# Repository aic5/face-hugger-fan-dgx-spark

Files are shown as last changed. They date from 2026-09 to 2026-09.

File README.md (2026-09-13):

# Face Hugger Fan for NVIDIA DGX Spark

An open hardware and software project for adding a temperature-controlled
140 mm fan to an NVIDIA DGX Spark. A Raspberry Pi Pico W drives a standard
12 V Noctua NF-A14 PWM fan, tracks CPU/GPU temperature in a local dashboard, and accepts temperature
telemetry from a small Linux service running on the DGX Spark. 

The RPi Pico W controls the fan automatically following a temperature curve set in the dashboard. It only comes on when it is needed and the fan is powered by a USB port in the DGX directly. No opening the DGX. No excessive noise. It comes on as needed. Set and forget. 

The name of this repo comes from the printed fan mount and arms, which wrap around the DGX
Spark a little like a face hugger. It makes the DGX Spark not as pretty, but also about 4-5C cooler.

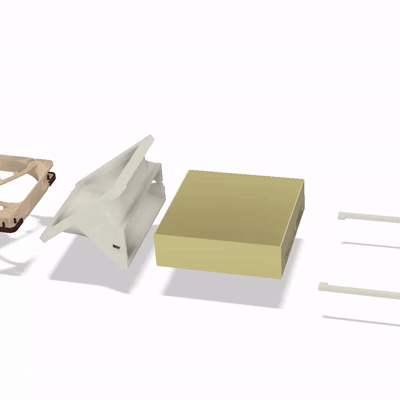
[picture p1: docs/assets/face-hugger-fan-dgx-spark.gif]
Animated exploded view of the Face Hugger Fan assembly


> [!CAUTION]
> This is an experimental, independently developed accessory. It is not endorsed
> by NVIDIA, Raspberry Pi, or Noctua, and it does not replace the DGX Spark's
> internal thermal management. Disconnect power before wiring. The fan motor is
> the only part of this design that receives 12 V. Use this at your own risk.

## Real build and printable parts

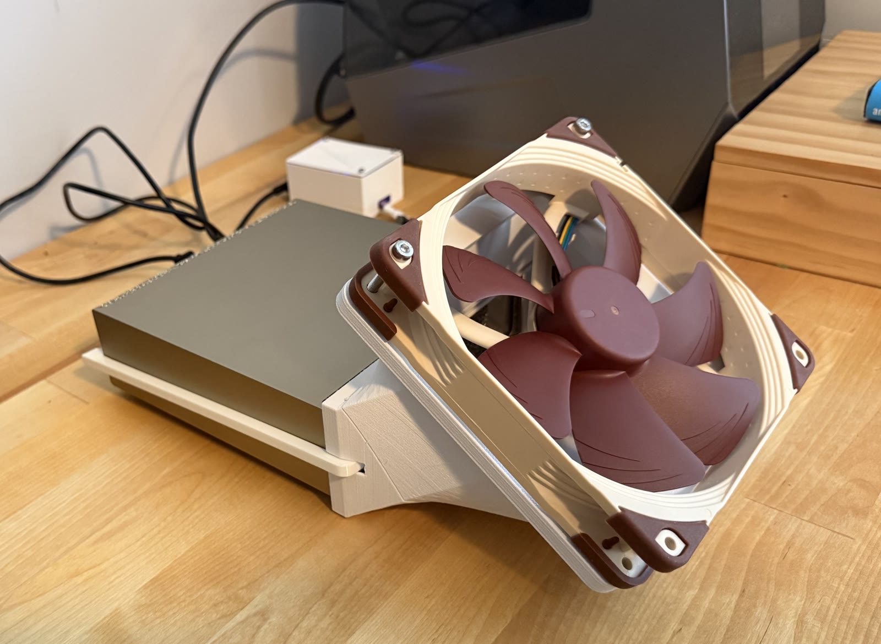
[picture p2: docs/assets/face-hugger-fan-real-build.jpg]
Assembled Face Hugger Fan mounted beside an NVIDIA DGX Spark


The photograph above shows the real assembled prototype. Both printable model
files are included in this repository:

- [Download the fan body / cover STL](hardware/stl/face-hugger-fan-dgx-spark-body.stl)
- [Download the two-arm set STL](hardware/stl/face-hugger-fan-dgx-spark-arms.stl)

See the [STL notes](hardware/stl/README.md) for dimensions, triangle counts,
checksums, scale guidance, and the current printing and assembly caveats.

## What is here

- Raspberry Pi Pico W CircuitPython firmware
- DGX Spark temperature collection and fan-control service
- Password-protected local web dashboard and temperature curve editor
- Illustrated wiring guide for the Pico W, boost converter, and 4-wire fan
- Bill of materials and fan specifications
- A quick-start installation guide
- Thermal comparison results with and without the external fan
- Printable body and mounting-arm STL files
- Desktop tests and continuous integration

## How it works

```mermaid
flowchart LR
    D[DGX Spark<br/>CPU and GPU sensors] -->|Wi-Fi telemetry<br/>and renewed commands| P[Raspberry Pi Pico W]
    U[5 V USB power] --> B[5 V to 12 V<br/>boost converter]
    U --> P
    B -->|12 V motor power| F[Noctua NF-A14 PWM]
    P -->|25 kHz PWM on GP15| F
    F -->|tach pulses on GP13| P
    P --> W[Local web dashboard]
```

The Pico starts at full fan speed and returns to full speed if commands expire.
The DGX service reads CPU/GPU temperatures, evaluates the configured stepped fan
curve, and renews the selected PWM command every five seconds by default.

## Dashboard

The Pico hosts a responsive local dashboard for live CPU/GPU temperature,
estimated fan speed, PWM output, fan-curve editing, and 24-hour history. The view
below uses synthetic readings from the repository's test fixture; it contains no
live credentials or private network information.

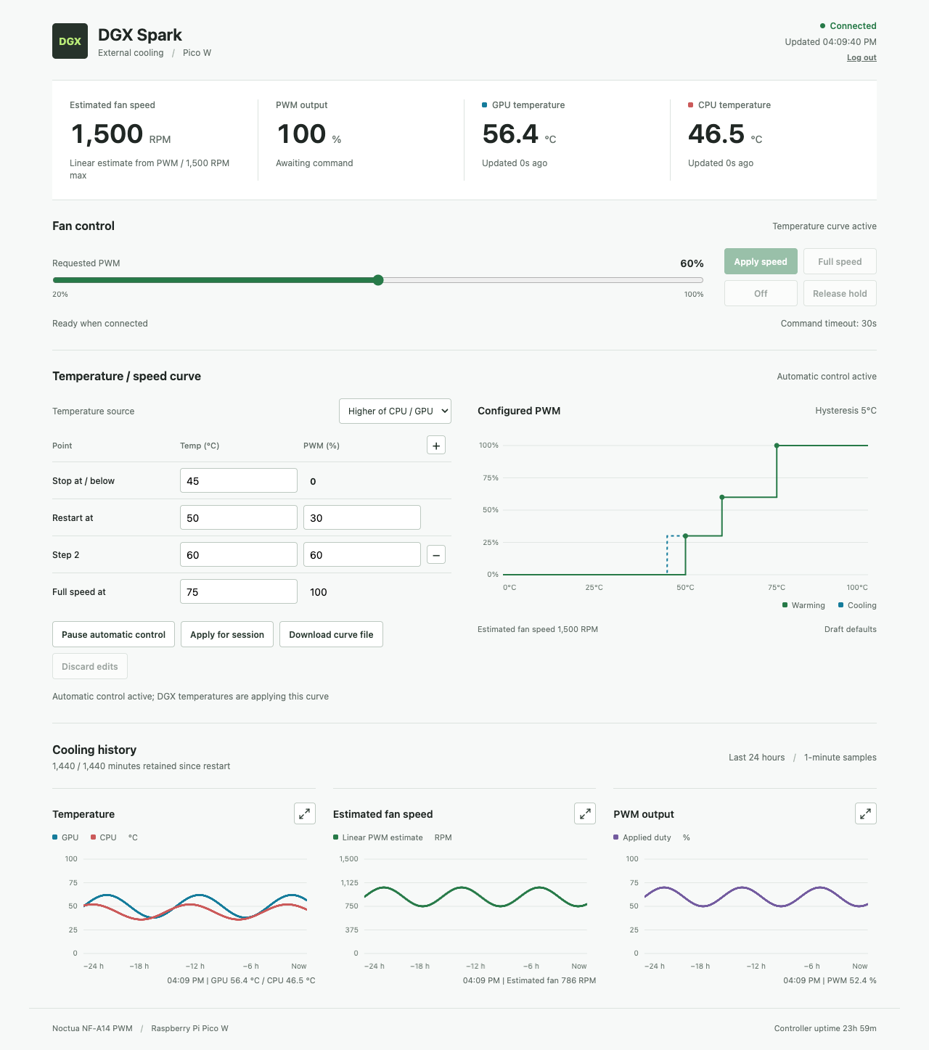
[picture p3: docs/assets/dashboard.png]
DGX Spark external fan controller dashboard


## Measured result

In the 13 September 2026 comparison, the external fan's clearest benefit was
lower peak temperature and less variation - not lower averages:

| Metric | GPU, no fan | GPU, with fan | Change | CPU, no fan | CPU, with fan | Change |
| --- | ---: | ---: | ---: | ---: | ---: | ---: |
| Maximum | 78.0 °C | 68.0 °C | **-10.0 °C** | 91.6 °C | 76.7 °C | **-14.9 °C** |
| Standard deviation | 11.2 °C | 7.3 °C | **-3.9 °C** | 14.8 °C | 9.3 °C | **-5.5 °C** |
| Average | 60.8 °C | 62.1 °C | +1.3 °C | 68.0 °C | 69.8 °C | +1.8 °C |

See [Thermal test results](docs/thermal-results.md) for all published statistics,
the original report, and the limitations of this comparison.

## Start here

### Parts links

The following Amazon links are affiliate links. I may receive a commission at
no additional cost to you if you make a purchase through them.

- [Noctua NF-A14 PWM computer fan](https://link.amazon/B0ex7c04A)
- [Raspberry Pi Pico W](https://amzn.to/4h3aFq5)
- [12 V DC boost converter](https://amzn.to/3UTugBN)

1. Read the [bill of materials](docs/bom.md) and obtain the parts.
2. Read the complete [illustrated wiring guide](docs/wiring.html) before connecting power.
3. Follow the [quick-start guide](docs/quick-start.md) to install the Pico firmware
   and the DGX service.
4. Review the [fan specifications](docs/fan-specifications.md) before substituting
   a different fan.
5. Read the [detailed software reference](docs/software-reference.md) for API,
   dashboard, fan-curve, failure-mode, and test documentation.

The printable body and two-arm set are available in [hardware/stl/](hardware/stl/).
STL files do not encode units, so read the model notes and verify dimensions in
your slicer before printing.

## Repository map

| Path | Contents |
| --- | --- |
| `code.py`, `fan_*.py`, `wifi_control.py` | Pico W firmware |
| `fan_curve.json` | Editable default temperature curve |
| `www/` | Pico-hosted dashboard |
| `lib/` | CircuitPython HTTP server dependency and its license |
| `dgx/` | DGX Spark telemetry script, environment template, and systemd service |
| `docs/` | BOM, wiring, installation, specifications, and test results |
| `hardware/stl/` | Printable body and two-arm STL models, with model metadata |
| `tests/` | Desktop unit and integration tests |

## Project status

This is a working experimental build, released so others can reproduce, inspect,
and improve it. The software includes fail-safe behavior, but no software can
guarantee cooling during loss of power, a microcontroller reset, wiring failure,
or a frozen processor. Validate your own assembly before unattended use.

## Contributing and license

Bug reports, test results, documentation improvements, and hardware adaptations
are welcome; see [CONTRIBUTING.md](CONTRIBUTING.md). The original project code and
documentation are licensed under the [MIT License](LICENSE). Bundled third-party
components retain their own licenses; see [THIRD_PARTY_NOTICES.md](THIRD_PARTY_NOTICES.md).

NVIDIA, DGX, Raspberry Pi, Noctua, and other names are trademarks of their
respective owners. Their use here identifies compatibility only.

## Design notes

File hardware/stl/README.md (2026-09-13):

# Printable body and arms

This directory contains the two supplied binary STL exports for the Face Hugger
Fan assembly:

- [face-hugger-fan-dgx-spark-body.stl](face-hugger-fan-dgx-spark-body.stl) - fan
  body / cover
- [face-hugger-fan-dgx-spark-arms.stl](face-hugger-fan-dgx-spark-arms.stl) -
  the arm set

## File checks

| File | Binary STL triangles | File size | Geometry extents (X × Y × Z) |
| --- | ---: | ---: | ---: |
| Body | 12,554 | 627,784 bytes | 117.39 × 157.70 × 103.55 model units |
| Arms | 1,732 | 86,684 bytes | 165.10 × 161.52 × 5.66 model units |

Both files have internally consistent binary STL sizes. STL stores unitless
coordinates; the geometry appears intended for millimetres, but verify scale and
fit in the slicer before printing.

SHA-256 checksums:

```text
9c1f025c2a4f044e721fbc4a8768e0ce10d8e4b5323c02de7012720d822ea69a  face-hugger-fan-dgx-spark-body.stl
e7a46a85c022b9e21589a93c3937379717238a1be09f6edae005b530b0292813  face-hugger-fan-dgx-spark-arms.stl
```

## Printing and assembly status

The source material does not yet include a validated slicer profile, source CAD,
material choice, support strategy, fastener list, or step-by-step mechanical
assembly guide. Until those are documented:

- inspect the imported scale against the 140 mm fan and the dimensions above;
- choose material with appropriate heat resistance and creep performance;
- orient and support the parts based on load paths and your printer's behavior;
- keep printed parts and fasteners clear of the blades and DGX vents;
- protect the Pico antenna from nearby metal and dense wiring; and
- treat the assembly as a prototype that requires inspection before each use.

The models are distributed under the repository's MIT License. Editable CAD and
tested print settings are welcome as future contributions.

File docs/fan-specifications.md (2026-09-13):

# Fan specifications

The reference build uses the **Noctua NF-A14 PWM standard 12 V model**. Similar
product names exist for different voltage and connector variants, so check the
label before wiring.

## Manufacturer specifications

| Property | Published value |
| --- | --- |
| Form factor | 140 × 140 × 25 mm without anti-vibration pads |
| Size with anti-vibration pads | 141 × 141 × 27 mm |
| Mounting-hole spacing | 124.5 × 124.5 mm |
| Connector | 4-pin PWM |
| Rated voltage | 12 V |
| Maximum operating voltage | 13.2 V |
| Starting voltage | 7 V |
| Speed range | 0-1,500 RPM |
| Speed at 20% PWM | 300 RPM |
| Maximum airflow | 140.2 m³/h / 82.52 CFM |
| Maximum static pressure | 2.08 mm H₂O |
| Maximum acoustical noise | 24.6 dB(A) |
| Typical / maximum input power | 1.19 W / 1.56 W |
| Typical / maximum input current | 0.10 A / 0.13 A |
| Tachometer | Open-collector, 2 pulses per revolution |
| Fan operating temperature | -10 °C to +70 °C |

Values are from the linked manufacturer pages as accessed in September 2026.
The project has not independently certified every specification.

## Pinout used by this project

| Fan pin | Standard wire colour | Function | Project connection |
| ---: | --- | --- | --- |
| 1 | Black | Ground | Boost `OUT-` and Pico ground |
| 2 | Yellow | Motor voltage | Regulated boost `OUT+` at 12 V |
| 3 | Green | RPM / tachometer | Pico GP13, physical pin 17, with 1 kΩ pull-up and 1 µF filter |
| 4 | Blue | PWM command | Pico GP15, physical pin 20 |

Wire colour is only a cross-check. Use the keyed connector and manufacturer
pin numbering; the apparent left-to-right order reverses between mating-face and
wire-side views.

## How the firmware uses it

- PWM output: direct, non-inverted 3.3 V logic at 25 kHz
- Accepted command: off (`0%`) or `20-100%`
- Startup: 100% for two seconds when starting from off
- Default remote fail-safe: 100% until valid commands arrive and after timeout
- RPM estimate: tach falling edges divided by two pulses per revolution

PWM duty is a command, not closed-loop RPM regulation. The dashboard also shows
a simple linear RPM estimate for charting, while the API keeps the physical tach
reading separate.

## References

- [NF-A14 PWM specifications](https://www.noctua.at/en/products/nf-a14-pwm/specifications)
- [Noctua microcontroller PWM/RPM guide](https://www.noctua.at/en/support/faqs/microcontroller-guide-pwm-setup-and-rpm-monitoring)
- [Noctua 4-wire PWM specification](https://cdn.noctua.at/media/Noctua_PWM_specifications_white_paper.pdf)

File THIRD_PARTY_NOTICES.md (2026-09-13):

# Third-party notices

The repository includes third-party components under their original terms:

- `lib/adafruit_httpserver/`: compiled Adafruit CircuitPython HTTPServer 4.8.2
  modules. See `lib/adafruit_httpserver/LICENSE`.
- `www/maximize-2.svg` and `www/x.svg`: Lucide icons. See `www/LUCIDE-LICENSE`.

Manufacturer names, product names, and linked documents belong to their
respective owners. Links and compatibility descriptions do not incorporate
those documents into this repository's MIT License.

The thermal comparison PDF under `docs/results/` is original project material
distributed with this repository.

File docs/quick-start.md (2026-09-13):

# Quick start

This guide takes the reference build from an empty Pico W to automatic control.
Read the [illustrated wiring guide](wiring.html) before assembling hardware.

## 1. Wire and bench-test the electronics

With all power disconnected:

| Connection | Destination |
| --- | --- |
| Fan black / pin 1 | Boost `OUT-` and Pico GND, physical pin 18 |
| Fan yellow / pin 2 | Boost `OUT+`, regulated **12 V only** |
| Fan green / pin 3 | Pico GP13, physical pin 17 |
| Fan blue / pin 4 | Pico GP15, physical pin 20 |
| 1 kΩ resistor | Pico 3V3(OUT), pin 36, to the GP13/green tach node |
| 1 µF non-polarized capacitor | GP13/green tach node to ground |

Power the Pico through its micro-USB socket for the simplest first build. Feed
the boost converter from a separately rated 5 V branch, join the grounds, and
test the converter at 12 V before connecting the fan. Never put 12 V on the Pico,
the blue PWM lead, or the green tach lead.

## 2. Install CircuitPython on the Pico W

1. Download the current stable UF2 from the
   [CircuitPython Pico W page](https://circuitpython.org/board/raspberry_pi_pico_w/).
   This repository was developed against CircuitPython 10.3.0.
2. Hold the Pico's `BOOTSEL` button while connecting USB.
3. Copy the UF2 to the `RPI-RP2` drive. The board restarts as `CIRCUITPY`.

## 3. Configure the Pico

Copy `settings.toml.example` to `settings.toml` and set:

```toml
WIFI_ENABLED = "1"
WIFI_SSID = "YOUR_2_4_GHZ_NETWORK"
WIFI_PASSWORD = "YOUR_WIFI_PASSWORD"
FAN_WEB_USERNAME = "YOUR_DASHBOARD_USERNAME"
FAN_WEB_PASSWORD = "A_LONG_UNIQUE_PASSWORD"
DEVICE_NAME = "dgx-fan"
FAN_COMMAND_TIMEOUT = 30
```

Do not commit `settings.toml`; it is ignored by Git.

Copy these items to the root of `CIRCUITPY`:

```text
code.py
fan_control.py
fan_curve.py
fan_curve.json
fan_history.py
wifi_control.py
settings.toml
lib/
www/
```

Replace old copies as a set. CircuitPython reloads automatically. The serial
console prints the board's IP address and, when mDNS works on the network, the
default name `http://dgx-fan.local`.

## 4. First fan test

1. Keep the fan power off and let the Pico finish booting.
2. Apply the regulated 12 V fan supply.
3. Open the Pico address from a browser on the same trusted LAN and sign in.
4. Pause automatic control, request full speed, request a middle duty, then
   request off. Watch for blade clearance, stable 12 V output, Pico resets, heat,
   or abnormal noise.
5. Release manual control. Until the DGX service is running, the fail-safe may
   restore full speed after the command timeout; this is expected.

## 5. Install the DGX Spark service

From the cloned repository on the DGX, first verify sensor discovery:

```sh
python3 dgx/dgx_fan_telemetry.py --probe
```

Then install the service:

```sh
sudo install -d -m 755 /opt/dgx-fan
sudo install -m 755 dgx/dgx_fan_telemetry.py fan_curve.py /opt/dgx-fan/
sudo install -m 600 dgx/dgx-fan-telemetry.env.example /etc/dgx-fan-telemetry.env
sudo install -m 644 dgx/dgx-fan-telemetry.service /etc/systemd/system/
sudoedit /etc/dgx-fan-telemetry.env
sudo systemctl daemon-reload
sudo systemctl enable --now dgx-fan-telemetry.service
```

Set the Pico URL and the same dashboard username/password in
`/etc/dgx-fan-telemetry.env`. Check operation with:

```sh
systemctl status dgx-fan-telemetry.service
journalctl -u dgx-fan-telemetry.service -n 30 --no-pager
```

The service sends a fresh command every five seconds by default. The Pico holds
full speed if no valid command has arrived or if the command age reaches the
30-second default timeout.

## 6. Tune carefully

The included curve is an illustrative starting point, not an NVIDIA thermal
recommendation:

| Selected CPU/GPU temperature | Requested fan output |
| --- | ---: |
| At or below 45 °C | Off |
| At or above 50 °C | 30% |
| At or above 60 °C | 60% |
| At or above 75 °C | 100% |

Use the dashboard to test a curve, then download its JSON and replace
`CIRCUITPY/fan_curve.json` if you want it to survive a reboot. Confirm the fan's
minimum reliable duty and collect your own before/after data under matched
workloads.

## Troubleshooting

| Symptom | First checks |
| --- | --- |
| Fan does not run | Measured 12 V and polarity at the fan, requested duty, blade clearance |
| Fan runs but RPM is zero | Green lead on GP13, shared ground, 1 kΩ pull-up, 1 µF capacitor |
| Pico resets as fan starts | 5 V source, cable loss, converter continuous/startup rating, loose connections |
| Dashboard unavailable | 2.4 GHz network, serial-console IP, credentials, complete `www/` and `lib/` copies |
| Service holds full speed | Pico reachability, `/etc/dgx-fan-telemetry.env`, discovered CPU/GPU sensors, service logs |

For API details and failure behavior, continue to the
[software reference](software-reference.md).

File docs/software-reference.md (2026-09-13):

# Software reference

CircuitPython firmware for a Raspberry Pi Pico W controlling a 12 V Noctua NF-A14
PWM fan. The board can join a 2.4 GHz Wi-Fi network and accept local HTTP commands
to turn the fan off or set its PWM duty. The DGX Linux service collects CPU/GPU
temperatures, applies the configured temperature curve, and sends renewed PWM
commands to the Pico. USB currently supplies power and a serial console; there is not yet a
USB serial command protocol.

This project targets CircuitPython 10.3.0 for Raspberry Pi Pico W. Wi-Fi control
uses Adafruit HTTPServer (desktop integration verified with 4.8.2). A settings-backed
login creates an in-memory browser session; no control token is used.
The hardware is experimental; validate each assembly before unattended use.

## Project files

| File | Role |
| --- | --- |
| `code.py` | Board entry point, hardware setup, main loop |
| `fan_control.py` | Duty, startup boost, RPM and command timeout |
| `fan_history.py` | Bounded minute history and DGX telemetry freshness |
| `fan_curve.py` | Shared validated stepped policy and automatic-control state |
| `fan_curve.json` | Non-secret, editable temperature and PWM thresholds |
| `wifi_control.py` | Wi-Fi reconnect, optional mDNS and HTTP API |
| `www/` | Self-contained browser dashboard, styles and charts |
| `dgx/dgx_fan_telemetry.py` | DGX temperature probe and Pico telemetry sender |
| `dgx/dgx-fan-telemetry.service` | Hardened systemd service definition |
| `dgx/dgx-fan-telemetry.env.example` | DGX-side service configuration template |
| `settings.toml.example` | Configuration template, with no credentials |
| `settings.toml` | Local configuration, ignored by Git |
| `lib/adafruit_httpserver/` | Included CircuitPython 10.x HTTPServer 4.8.2 library |
| `tests/` | Simulated hardware and real localhost HTTP checks |

## Wiring

See the [illustrated wiring reference](docs/wiring.html) for connection diagrams,
Pico physical pin locations, shared USB power precautions and a first-power-up
checklist. It also documents the proposed USB-C breakout variant: verified 5 V
from `V` through an added Schottky diode to VSYS (pin 39), common GND (pin 38),
and optional USB `D+`/`D-` to TP3/TP2. The supplied product image identifies an
ANMBEST JRC-B008 breakout (`G`, `D+`, `D-`, `V`); its independent CC pull-downs
and 5 V operation still need verification before connection to the Pico. Open
the HTML file directly in a browser; no server is required.

Disconnect power before wiring. The fan uses a keyed 4-pin PC fan plug.
Use a mating 4-pin PC PWM fan header/breakout or extension with accessible wires.
Verify pin numbering against Noctua's connector diagram. Do not assume left-to-right
order: viewing the plug from the wire side reverses it. The plug is not USB.

| Fan pin | Typical colour | Connection |
| --- | --- | --- |
| 1, ground | Black | 12 V supply negative AND Pico GND, physical pin 18 |
| 2, motor supply | Yellow | Regulated +12 V supply only |
| 3, tachometer | Green | GP13, physical pin 17, with the pull-up/filter below |
| 4, PWM control | Blue | GP15, physical pin 20 |

For the simple USB-cable setup, power the Pico through its micro-USB socket.
For the VSYS/USB-C breakout variant, follow the illustrated guide instead; never
connect two USB hosts to the socket and test pads simultaneously. The motor requires a separate
regulated 12 V source, such as an adapter rated for at least 0.5 A or a suitable
USB 5 V-to-12 V boost converter. Never connect 12 V to the Pico or to fan pin 4.
Fan ground, supply negative and Pico ground must be joined. Do not pulse the fan's
motor supply: speed control uses only the blue wire.

A shared USB-C source can supply the Pico's 5 V/data branch and a separate
5 V-to-12 V boost branch for the fan. Verify the converter, cable/hub and USB
source current ratings, including startup margin. The NF-A14 PWM is rated up to
1.56 W (0.13 A at 12 V); at an illustrative 85% boost efficiency, that is about
0.37 A drawn from 5 V for the fan alone, plus the Pico's consumption. The boost
output must never connect to the Pico's USB/VSYS/3V3/GPIO pins or backfeed USB VBUS.
A USB-C PD trigger selecting a voltage above 5 V is not equivalent to this split
5 V arrangement. Keep USB data connected to the Pico, and verify the actual wiring
and negotiated/advertised USB current before relying on one source for both loads.

Noctua supports a direct 3.3 V GPIO PWM signal. This program assumes that direct
connection, without an inverting transistor. No external PWM pull-up is needed.
For this wiring, power the Pico before the fan and turn the fan supply off before
unplugging the Pico. The software cannot guarantee full speed during power loss,
firmware flashing, resets or a processor freeze.

RPM monitoring is always enabled: connect green to GP13.
This changes the earlier MicroPython wiring: move green from GP14 (physical pin 19)
to GP13 (physical pin 17), and move its pull-up/filter components with it.
CircuitPython's RP2040 pulse counter needs a PWM channel B pin (an odd GPIO).
GP13 uses a different PWM slice from GP15, allowing counting and speed control
to operate together. Leave both GP12 and GP13 free of other PWM uses when counting.

The fan tachometer is an open-collector output and does not produce a HIGH voltage
by itself. Fit a **1 kΩ resistor from GP13 to 3V3(OUT), physical pin 36**, and a
**1 µF non-polarized capacitor from GP13 to ground**. These values follow Noctua's
current microcontroller guidance and provide a stronger, cleaner signal than the
Pico's internal pull-up alone. Never pull GP13 up to 5 V or 12 V. The fan emits
two pulses per revolution. Zero pulses do not distinguish a stopped fan, missing
fan power, a disconnected tach wire, or an incomplete pull-up/ground circuit.

## Install on the Pico

1. Install the [CircuitPython Pico W firmware](https://circuitpython.org/board/raspberry_pi_pico_w/).
   Preserve existing board files first when changing firmware. Hold BOOTSEL while
   connecting USB, then transfer the UF2 to RPI-RP2. The board reappears as CIRCUITPY.
2. Transfer this project's included `lib/` folder to `CIRCUITPY/lib/`.
   It contains the official CircuitPython 10.x build of HTTPServer 4.8.2;
   no separate library download is needed.
   Standalone mode does not require this library.
3. Set your network details in the local `settings.toml`. A blank file is provided
   in this workspace; when cloning the repository, start from `settings.toml.example`.
   Enter `WIFI_SSID`, `WIFI_PASSWORD`, `FAN_WEB_USERNAME`, and
   `FAN_WEB_PASSWORD`. Keep `WIFI_ENABLED = "1"`.
4. Transfer `code.py`, `fan_control.py`, `fan_history.py`, `fan_curve.py`,
   `fan_curve.json`, `wifi_control.py` and
   `settings.toml` to the root of CIRCUITPY, and replace `CIRCUITPY/www/` with
   this project's complete `www/` folder. If the old control-token field still
   appears, the board is serving an earlier web bundle; restart the Pico and
   hard-refresh the browser after transferring all of these files together.
   Preserve your existing board settings when updating code. Do not transfer Git metadata or the tests. Remove the
   old MicroPython `main.py` if it is still present, after preserving needed changes.
5. CircuitPython reloads after file changes. In Thonny's CircuitPython serial
   console, the board prints its IP address and, when available, its mDNS name.
   By default the API is at `http://dgx-fan.local`; use the printed IP if name
   resolution is unavailable on the board, network or DGX.
6. With wiring checked and Pico power present, apply the fan's 12 V supply.
   Wi-Fi mode holds full speed until the DGX service sends its first curve command.

Open the board's IP address in a browser for the dashboard, or use the HTTP API
below. There is no remote firmware upload endpoint. An ordinary USB data cable can still provide power and
access to CIRCUITPY and the console; Wi-Fi does not supply electrical power.

The login and API use plain HTTP, so credentials and session cookies are not
encrypted in transit. Use the controller only on an isolated, trusted LAN; do not
expose it to guest Wi-Fi or the internet. Writes require
`Content-Type: application/json`, and cross-origin browser access is not enabled. Neither
credentials nor firmware files are served.

## Dashboard and history

Opening `/` redirects to the login page until the configured username and password
are accepted. The Pico then sets an HttpOnly, SameSite session cookie, so the
dashboard does not ask again while that browser session and controller boot remain
active. Logging out, closing the browser session, or restarting the Pico requires
a new login. The dashboard shows estimated fan RPM, applied PWM, controller state,
and DGX GPU/CPU temperatures. No control token or CORS access is used.

The dashboard estimates the NF-A14 speed linearly from its applied PWM using the
fan's rated 1,500 RPM maximum: 0% displays 0 RPM, 60% displays 900 RPM, and 100%
displays 1,500 RPM. The 24-hour RPM chart applies the same calculation to retained
PWM samples. This is a display estimate, not proof that the fan is rotating. The
API and USB diagnostics retain the separate physical tachometer reading for later
troubleshooting.

The three history charts share one row on desktop and stack on narrow screens.
Each expand icon opens a larger modal chart with temperature/RPM/PWM tabs. The
expanded chart uses the same live, minute-sampled history without extra API calls.
Its time-range controls show all retained data or fixed windows of 24 hours,
12 hours, 3 hours, 1 hour, 30 minutes or 15 minutes. The selection remains active
when switching chart tabs. Export CSV downloads the selected chart's timestamped
samples within the chosen range, with separate GPU/CPU columns for temperature.
Close it with the close button, Escape, or a click outside; keyboard focus returns
to the original expand button. Arrow keys switch the chart tabs.

Automatic temperature control starts enabled after a Pico or DGX service restart.
The Temperature / speed curve section has a button to pause or reactivate it.
While it is active, manual fan controls are disabled to avoid competing commands.
Pausing automatic control immediately selects the full-speed fallback; a manual
command can then be applied.

Apply speed, Full speed, and Off start a browser-held command. While visible and
connected, the page refreshes that command at most every five seconds (sooner for
short configured timeouts). Release hold requests full speed. Closing/hiding the
page or losing connectivity stops renewal; the existing command timeout then
requests full speed. A restart or observed conflicting command cancels the page's
hold. Status reads never renew commands.

The Pico stores one instantaneous sample per minute for at most 1,440 minutes,
including when no browser is open. Four packed arrays use 11,520 bytes for RPM,
GPU temperature, CPU temperature and PWM. History is RAM-only: reboot/reload
clears it and no flash writes occur. Charts always span 24 hours, leaving missing
data as gaps. Temperatures retain 0.1 C precision; PWM retains 0.01% precision.
Chart times are mapped from Pico monotonic time to the viewing browser's clock.
History is downloaded in pages of at most 120 samples to bound response memory.
Each row is `[minute, rpm, gpu_temperature_c, cpu_temperature_c, applied_duty]`.
Use `next_before` as the next request's `before` parameter until it is null.

DGX temperatures require the included sender; the Pico does not measure them.
The service sends a complete sensor snapshot and refreshes the curve command every
five seconds by default.
Omitted/null sensors are unavailable, and readings expire after 120 seconds.
The telemetry API alone does not renew the fan command timeout:

```sh
curl --fail-with-body http://dgx-fan.local/api/telemetry \
  -b fan-cookie.txt \
  -H "Content-Type: application/json" \
  -d '{"gpu_temperature_c":55.5,"cpu_temperature_c":48.2}'
```

The above values illustrate the schema, not measured DGX temperatures. The DGX
service reads the current curve after each snapshot and sends the selected duty.

## Temperature steps

The dashboard's Temperature / speed curve editor defines explicit Celsius
thresholds and stepped PWM output, not a continuous ramp or exact RPM targets.
Actual RPM remains a separate tachometer reading. The built-in draft and
`fan_curve.json` start with these **illustrative values, not recommended DGX
thermal limits**:

| Temperature | Requested output |
| --- | --- |
| At or below 45 C | Off (0%) |
| At or above 50 C | 30% PWM |
| At or above 60 C | 60% PWM |
| At or above 75 C | Full speed (100%) |

Between 45 and 50 C, a stopped fan stays off; an already running fan stays at
the first running step. This is the stop/restart hysteresis band. Between other
thresholds, the previous step is held: 59.9 C selects 30%, exactly 60 C selects
60%, and 74.9 C remains 60%. No interpolation is performed. On cooling below an
intermediate threshold, output returns to the preceding step.

You can select CPU, GPU, or the higher of both, set the stop temperature, edit
2-8 running steps, and add/remove intermediate steps. Temperatures must increase;
running PWM must not decrease, starts at 20% or higher, and only the final step
is 100%. The final temperature is the full-speed threshold. Confirm the lowest
usable PWM with your actual fan and power supply; PWM percentage is not a fixed
fraction of rated RPM. Startup boost and command-timeout protection remain unchanged.

`GET /api/curve` returns the current non-secret configuration and automatic-control
state. `POST /api/curve` replaces the curve for this running session only. Applying
a curve does not itself command the fan; the DGX service observes it on its next
five-second cycle. `POST /api/automatic` pauses or activates automatic control.
Transitions use full speed until a new valid curve or manual command arrives.
The DGX service retains running/off state for hysteresis and commands full speed
when a selected temperature is unavailable.

On boot the Pico loads `fan_curve.json`. Missing/invalid files use draft defaults
and log a warning. Automatic control defaults to enabled; the fan remains at the
full-speed fallback until the DGX service supplies a valid renewed command.
Curve downloads contain only the curve, never `settings.toml` credentials.
To retain web edits across restarts, use Download curve file and replace
`CIRCUITPY/fan_curve.json` with that file (also keep the development copy updated).
The web UI deliberately does not write the host-owned USB filesystem or silently
change USB storage permissions. Apply for session therefore does not persist.

If the page reports `Curve API missing (404)`, it is reaching a server without
the new curve route. Updating files on CIRCUITPY can update the served HTML/JS
before the running Python server reloads, especially while using Thonny. Confirm
the firmware modules have been copied, restart the Pico, then use Retry or refresh
the page. A missing/invalid `fan_curve.json` alone does not cause a 404: the current
firmware returns its draft defaults. Other malformed responses and connection
failures are reported separately and do not block the live fan status display.

## Settings

| Setting | Default / meaning |
| --- | --- |
| `WIFI_ENABLED` | `"1"` in template; absent settings defaults to standalone |
| `WIFI_SSID`, `WIFI_PASSWORD` | Your 2.4 GHz network; required in Wi-Fi mode |
| `FAN_WEB_USERNAME`, `FAN_WEB_PASSWORD` | Dashboard/API login; both required in Wi-Fi mode |
| `DEVICE_NAME` | `"dgx-fan"`; lowercase hostname, no `.local` suffix |
| `FAN_HTTP_PORT` | `80` |
| `WIFI_IPV4_ADDRESS`, `WIFI_IPV4_NETMASK`, `WIFI_IPV4_GATEWAY`, `WIFI_IPV4_DNS` | Optional static network configuration; omit all four to use DHCP |
| `FAN_COMMAND_TIMEOUT` | `30` seconds; allowed 5-300 |
| `FAN_DUTY_PERCENT` | `60`; standalone setting only |

For a local test without networking, set `WIFI_ENABLED = "0"`. The fan starts
at full speed for two seconds and then runs at `FAN_DUTY_PERCENT`.
That value, and all API duty values, must be `0` (off) or `20` through `100`.
PWM percentage is a command, not an exact percentage of maximum RPM.

## Control from the DGX

### Temperature tracking service

The telemetry service uses `nvidia-smi` for GPU temperature and selects the
hottest Linux thermal zone whose name identifies a CPU, SoC or package sensor.
It accepts a zone override for platforms with unusual sensor names. Run its
read-only probe on the DGX before installation:

```sh
python3 dgx/dgx_fan_telemetry.py --probe
```

Install the script, environment template and service:

```sh
sudo install -d -m 755 /opt/dgx-fan
sudo install -m 755 dgx/dgx_fan_telemetry.py fan_curve.py /opt/dgx-fan/
sudo install -m 600 dgx/dgx-fan-telemetry.env.example /etc/dgx-fan-telemetry.env
sudo install -m 644 dgx/dgx-fan-telemetry.service /etc/systemd/system/
sudoedit /etc/dgx-fan-telemetry.env
sudo systemctl daemon-reload
sudo systemctl enable --now dgx-fan-telemetry.service
```

Set the Pico URL and dashboard username/password in the environment file. The
service never logs credentials. It automatically logs in again when its session
is missing or the Pico has restarted. Confirm delivery with:

```sh
systemctl status dgx-fan-telemetry.service
journalctl -u dgx-fan-telemetry.service -n 30 --no-pager
```

`DGX_FAN_AUTOMATIC_DEFAULT=1` makes each service start activate the curve. The
dashboard can pause it for the current run; restarting the service or DGX restores
the configured default. The service polls every five seconds so its commands remain
well inside the Pico's 30-second timeout. The Pico's timeout and full-speed fallback
remain authoritative if the service or network fails.

### Manual API control

The control and telemetry APIs use the same login session as the dashboard.
Command-line clients can log in once and reuse the returned cookie. Replace the
hostname with the printed IP when needed.

Log in and store the session cookie:

```sh
curl --fail-with-body http://dgx-fan.local/api/login \
  -c fan-cookie.txt \
  -H "Content-Type: application/json" \
  -d '{"username":"YOUR_USERNAME","password":"YOUR_PASSWORD"}'
```

Read status:

```sh
curl --fail-with-body http://dgx-fan.local/api/status -b fan-cookie.txt
```

Set 60% PWM:

```sh
curl --fail-with-body http://dgx-fan.local/api/fan \
  -b fan-cookie.txt \
  -H "Content-Type: application/json" \
  -d '{"duty":60}'
```

Use `{"duty":0}` to turn off, or `{"duty":100}` for maximum airflow.
A command response includes the requested duty, applied duty, state and measured
tachometer RPM. RPM is `null` when the counter is unavailable or no sample has been collected.
An RPM of zero with a nonzero command could mean a stopped fan, missing power
or disconnected tach wire; it does not uniquely identify the cause.

**Commands expire after 30 seconds by default, including off commands.**
The automatic controller resends its selected duty every 5 seconds, even
when temperature and speed have not changed. Status reads and invalid commands
do not renew this timeout.

When restarting from off, the Pico applies full speed for two seconds before
settling at the requested duty. Resending the same command during startup does
not keep extending the boost. An off command takes effect immediately.

## Connection and error behavior

- Wi-Fi disconnect or an expired command requests full speed.
- Static assets are cached by the browser for one hour. Versioned asset URLs make
  firmware updates take effect without serving CSS and JavaScript on every visit.
- The dashboard loads its stylesheet, program and live requests in sequence to
  avoid the Pico W networking slowdown caused by parallel browser connections.
- A browser that abandons a static-file download is disconnected after three
  seconds instead of being allowed to freeze the Pico's single HTTP loop.
- The board retries Wi-Fi connections and rebinds the HTTP listener after reconnection.
  Each connection attempt has a 5-second timeout and failed attempts wait 10 seconds.
- Reconnection does not restore an old off/slow command. The DGX must issue a new one.
- No fan or wires are needed to boot. An unwired tach input reports zero after
  its first sample. PWM output alone cannot detect whether a fan is spinning.
- The console prints the initial PWM/RPM/state status, then only when one of those
  values changes. Unchanged status is not repeated; startup and error messages remain.
- Tach debugging additionally prints `TACH GP13 (pin 17)` about every five seconds,
  including when there are zero pulses. It reports the raw cumulative falling-edge
  count, pulses during the actual elapsed window, window RPM (two pulses/revolution)
  and applied PWM. It observes the existing counter without resetting it or taking
  over GP13. This is a pulse count, not an instantaneous HIGH/LOW or voltage reading.
  For example: `total=250 | pulses=250 / 5.00s | window_RPM=1500 | PWM=60%`.
  If counter initialization failed, the diagnostic says unavailable.
- Invalid settings or unavailable Wi-Fi libraries finish boot with a 100% PWM
  fallback. The console identifies invalid settings
  without printing credentials. Fix the reported setting/library and reload.
  Set `WIFI_ENABLED = "0"` to test standalone operation without network configuration.
- RPM counter initialization failure disables RPM sensing, not the controller.
  An unwired tach input with its pull-up enabled will read zero after sampling;
  unavailable sensing reports `None` in the console (`null` in the API).
- Unexpected application exceptions still hold full PWM until reload.
- No settings file selects standalone mode; an installed file that enables Wi-Fi
  but lacks credentials does not silently fall back to a slower standalone speed.
- A powered, running controller is required for these software fallbacks. They do
  not cover failed imports before hardware setup, PWM initialization failure,
  firmware flashing, resets, power loss or a frozen processor.
- Ctrl+C stops the program and releases PWM. CircuitPython resets outputs on
  program exit/reload. Check actual fan behavior in those states on the assembled unit.

These rules control only the external fan. They do not replace the DGX's internal
thermal management. Temperature bands and hysteresis belong in the later Linux service.

## Verification

Core state tests need only desktop Python:

```sh
python3 -m unittest discover -s tests -v
```

HTTP tests skip when their desktop dependency is absent. To run all checks,
including real HTTP requests against a localhost listener:

```sh
python3 -m venv .venv
.venv/bin/python -m pip install -r requirements-test.txt
.venv/bin/python -m unittest discover -s tests -v
```

The tests cover startup, off/on, RPM, counter wrap, stale commands, login sessions,
bad requests, Wi-Fi reconnect, socket failures, history rollover, telemetry expiry,
DGX sensor selection, DGX reauthentication, and public dashboard isolation from
credentials. They do not test RF reception, electrical signals, memory usage on
the board, or the physical fan.

For optional browser checks, install Playwright in your desktop Node environment
and Chrome, then run `FAN_TEST_PYTHON=.venv/bin/python node tests/test_dashboard.cjs`.
This starts a temporary localhost fixture, verifies controls and desktop/mobile
charts, modal keyboard/focus behavior, and curve-error recovery, writes screenshots
under `/private/tmp/dgx-fan-dashboard`, and stops it.
The synthetic 24-hour readings exist only in `tests/serve_dashboard.py`, never
in the firmware or production dashboard.

## References

- [Noctua microcontroller guide](https://www.noctua.at/en/support/faqs/microcontroller-guide-pwm-setup-and-rpm-monitoring)
- [Noctua connector and PWM specification](https://cdn.noctua.at/media/Noctua_PWM_specifications_white_paper.pdf)
- [NF-A14 PWM electrical specifications](https://www.noctua.at/en/products/nf-a14-pwm/specifications)
- [Pico W physical pinout](https://datasheets.raspberrypi.com/picow/PicoW-A4-Pinout.pdf)
- [CircuitPython for Pico W](https://circuitpython.org/board/raspberry_pi_pico_w/)
- [CircuitPython PWM output](https://docs.circuitpython.org/en/latest/shared-bindings/pwmio/)
- [CircuitPython pulse counter restrictions](https://docs.circuitpython.org/en/latest/shared-bindings/countio/)
- [CircuitPython Wi-Fi API](https://docs.circuitpython.org/en/latest/shared-bindings/wifi/)
- [Adafruit HTTPServer examples](https://docs.circuitpython.org/projects/httpserver/en/latest/examples.html)
- Chart expand/close icons: Lucide 0.468.0, bundled locally with `www/LUCIDE-LICENSE`.

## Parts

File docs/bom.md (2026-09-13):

# Bill of materials

This bill covers the electronics and basic assembly described by the repository.
The printed cover and arms will be added under `hardware/stl/` separately.

## Required parts

| Qty. | Part | Specification / example | Notes |
| ---: | --- | --- | --- |
| 1 | NVIDIA DGX Spark | Target computer | The accessory does not modify the DGX internally. |
| 1 | Raspberry Pi Pico W | RP2040, 2.4 GHz Wi-Fi | A Pico WH is also plausible if its fitted headers suit the assembly, but this has not been verified. |
| 1 | 140 mm 4-wire PWM fan | **Noctua NF-A14 PWM, standard 12 V model** | Do not substitute the 5 V edition. See [fan specifications](fan-specifications.md). |
| 1 | 5 V-to-12 V DC boost converter | Regulated 12 V output; design for at least 0.5 A continuous output plus startup margin | The exact converter used in the prototype was not recorded in the source material. Verify its rating and set the output to 12 V before connecting anything else. |
| 1 | Regulated 5 V USB supply and cable | Enough capacity for the Pico, converter losses, and fan startup | The fan alone draws about 0.37 A from 5 V at 1.56 W and an illustrative 85% converter efficiency. Budget additional margin. |
| 1 | 4-pin PC fan mating header, breakout, or extension | Keyed, with accessible conductors | Do not cut the fan cable unless you accept the warranty and serviceability consequences. |
| 1 | 1 kΩ resistor | Tachometer pull-up | Connect from Pico 3V3(OUT) to the GP13/tach node. |
| 1 | 1 µF non-polarized capacitor | Tachometer filtering | Connect from the GP13/tach node to ground. |
| as needed | Insulated hookup wire | Suitable for signal and power currents | Keep motor wiring short and route its return directly to the supply. |
| as needed | Heat-shrink, terminals, strain relief, and fasteners | Appropriate to the assembly | No bare conductors should remain exposed. |
| 1 | Fan guard / printed cover | Sized for the 140 mm fan | Keep fingers, tools, cables, and the printed mount out of the blades. |

## Optional shared USB-C input variant

The illustrated wiring guide also documents a prototype arrangement using an
ANMBEST JRC-B008 USB-C receptacle breakout with pads marked `G`, `D+`, `D-`, and
`V`, plus an added Schottky diode on the Pico VSYS branch.

Treat that section as an advanced, unverified variant. The source material does
not establish that the board has the two independent 5.1 kΩ USB-C CC pull-downs
required of a basic power sink. Verify the actual board and 5 V output before
connecting it. Do not attach two USB hosts to the Pico USB socket and test pads.

## Tools

- Multimeter for polarity, continuity (with power off), 5 V input, and regulated
  12 V output checks
- Soldering equipment appropriate for the Pico/header assembly
- Small insulated hand tools
- A computer for installing CircuitPython and copying files
- A second device on the same trusted LAN for opening the dashboard

## Before buying substitutions

- The firmware assumes a standard 4-wire PC PWM interface at 25 kHz.
- The direct PWM signal is 3.3 V from GP15 and is not inverted.
- The tachometer is an open-collector, two-pulses-per-revolution signal.
- The configured lower limit is 20% PWM for a running fan; verify the actual
  minimum reliable duty with your fan and power supply.
- A converter's advertised input current or peak rating is not its continuous
  12 V output rating. Include cable losses and motor startup margin.

Manufacturer references:

- [Noctua NF-A14 PWM specifications](https://www.noctua.at/en/products/nf-a14-pwm/specifications)
- [Noctua PWM and RPM microcontroller guidance](https://www.noctua.at/en/support/faqs/microcontroller-guide-pwm-setup-and-rpm-monitoring)
- [Raspberry Pi Pico W documentation](https://www.raspberrypi.com/documentation/microcontrollers/pico-series.html)
- [CircuitPython for Raspberry Pi Pico W](https://circuitpython.org/board/raspberry_pi_pico_w/)

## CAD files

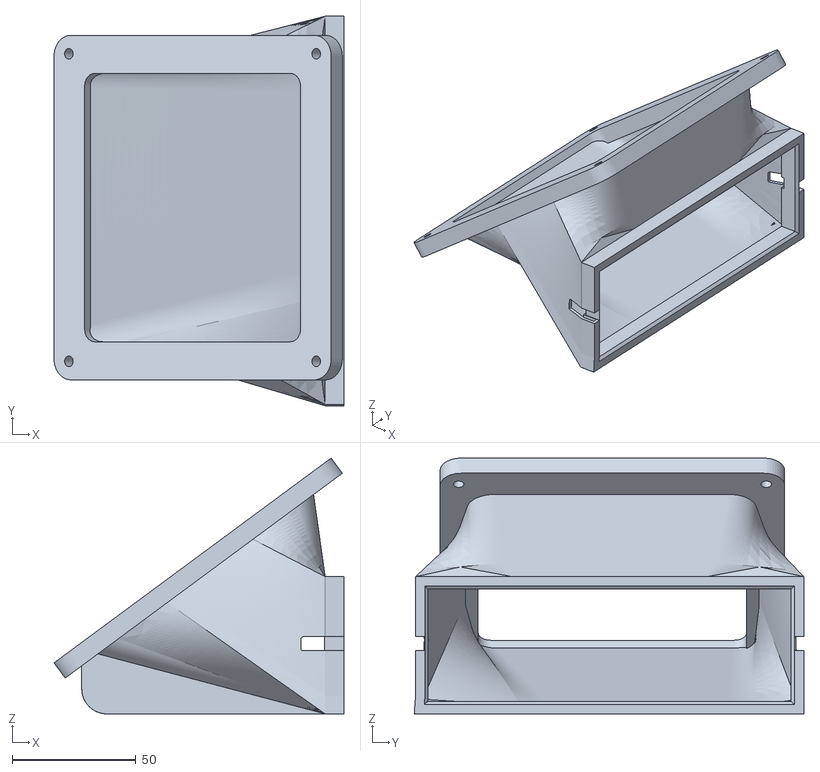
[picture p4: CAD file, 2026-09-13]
hardware/stl/face-hugger-fan-dgx-spark-body.stl
117.4 x 157.7 x 103.5

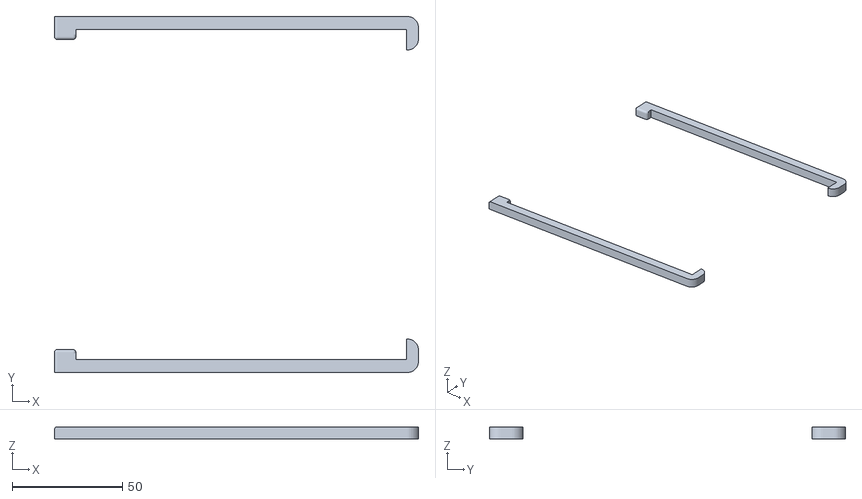
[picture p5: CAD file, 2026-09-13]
hardware/stl/face-hugger-fan-dgx-spark-arms.stl
165.1 x 161.5 x 5.66

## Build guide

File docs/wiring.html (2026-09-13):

Face Hugger Fan / Hardware reference / September 2026

# DGX Spark External Fan Wiring

Raspberry Pi Pico W · CircuitPython · Noctua NF-A14 PWM, standard 12 V model

Matches the current project pin assignments. The optional USB-C board is identified as an ANMBEST JRC-B008; its CC circuitry, the exact boost converter and each assembly still require verification.

12 V goes to the fan motor only. Never connect yellow / +12 V to a Pico pin or USB power rail. Disconnect all power before making or moving connections. Fit a fan guard and secure loose wires before testing.

Optional advanced variant. The simplest first build powers the Pico through its micro-USB socket. Use the USB-C/VSYS path below only after verifying the actual breakout, CC termination, voltage, diode orientation and power budget.

USB-C input board

## ANMBEST JRC-B008

The prototype source material identifies an ANMBEST JRC-B008 breakout with four exposed pads marked G, D+, D-, V. Confirm the markings and pad order on your actual board.

See the USB-C board connected to the Pico and boost converter.

The repository deliberately omits the third-party product photograph. CC termination and 5 V output still require verification.

01 / The four fan wires

## Fan-side connections

This first diagram covers the fan connector only. The USB-C board and VSYS supply are in the complete power diagram.

Use a mating 4-pin PC fan header or a labelled breakout/extension. The numbers below identify electrical functions, not a left-to-right view of your plug. The wire-side and mating-face views are mirrored; confirm the key and pin numbers before connecting.

Figure 1. Motor power and speed control are separate circuits. Wire functions: Noctua microcontroller guide (https://www.noctua.at/en/support/faqs/microcontroller-guide-pwm-setup-and-rpm-monitoring). GPIO choices: this project's code.py.

Fan pin / wire | Connect to | Comment
1 / Black | Boost OUT- and Pico GND, pin 18 | Common reference. Route motor return directly to the supply, not through Pico traces.
2 / Yellow | Boost OUT+, regulated 12 V | No connection to Pico power pins.
3 / Green | Pico GP13, pin 17 | RPM input; firmware sensing is automatic. Add the pull-up/filter in Figure 4.
4 / Blue | Pico GP15, pin 20 | Direct, non-inverted output used by this firmware.

Colour is a cross-check, not proof: chromax cables and third-party extensions may differ. Use Noctua's keyed connector drawing in the PWM specification, connector section (https://cdn.noctua.at/media/Noctua_PWM_specifications_white_paper.pdf).

02 / Power distribution

## USB-C board, Pico and boost converter

The supplied product image identifies an ANMBEST JRC-B008 female USB-C breakout, with pads marked G, D+, D- and V. Here, G means GND and V is USB VBUS. It appears to be a passive connector breakout, not a voltage regulator, boost converter or PD trigger. This circuit requires 5 V at V, measured before connecting VSYS. User-supplied product link (https://www.amazon.com/dp/B09WCSF8FC?th=1).

Pad locator. In this orientation, top to bottom: G, D+, D-, V. Rotating or flipping the board changes the apparent order. The product image lists approximately 15 × 9 mm; measure the actual part before designing its enclosure.

USB-C compatibility is not confirmed. A basic USB-C power-sink receptacle needs a separate 5.1 kΩ pull-down from CC1 to GND and another from CC2 to GND. Do not join CC1 and CC2 together. The supplied image shows an R1 area, but does not establish the values or presence of both independent pull-downs. These CC contacts are not among the four exposed pads. Do not assume that adding one resistor at R1 fixes the board. Renesas USB-C sink guidance (https://www.renesas.com/en/support/engineer-school/usb-power-delivery-03).

Before connecting the Pico or boost: confirm the CC circuit with the supplier's schematic or measurements on the unpowered board. Then test V-to-G using the intended DGX USB-C cable in both plug orientations. Expect approximately 5 V; no voltage or orientation-dependent power can indicate a CC problem. Successful power-up alone does not certify the board or establish available current. Use a breakout with documented independent CC pull-downs if this one cannot be verified.

The image's 20 V / 3 A figures are connector ratings, not a promised output voltage or permission to draw 3 A. The four exposed pads provide a USB 2.0-style data connection, not SuperSpeed lanes, regardless of the listing's USB 3.1 wording. The live Amazon page could not be retrieved; board-specific observations here come from your supplied product image.

The connection diagram below uses a different, logical terminal order for routing clarity. Follow pad labels, not drawing position. Pico power enters VSYS through the added diode; the separate boost branch provides fan motor power.

### USB-C board connections

Figure 2. Header-power arrangement; Pico micro-USB socket unused. TP1/TP2/TP3 are underside test pads, not header pins. Assumes a non-isolated boost converter. Confirm pad identity against the Pico W datasheet, sections 2.1 and 3.5 (https://datasheets.raspberrypi.com/picow/pico-w-datasheet.pdf) before soldering.

USB-C board terminal | Destination | Comment
V | Added Schottky diode, then VSYS / pin 39; separate branch to boost IN+ via switch | Verify 5 V first. Diode anode toward V, cathode/band toward VSYS. The motor branch must not pass through this diode or the Pico.
D+ | TP3 / USB DP | Optional until using USB data; not GP3 or physical pin 3.
D- | TP2 / USB DM | Optional until using USB data; not GP2 or physical pin 2.
G (GND) | GND / pin 38, common ground, and TP1 alongside the USB pair | Pin 38 and the fan's Pico ground at pin 18 are internally connected. Route motor return directly to the supply.

VSYS supply protection: the added Schottky diode prevents a later Pico USB power source from feeding back into the external V rail through VSYS. It is additional to the diode already on the Pico. Select a diode rated for Pico peak current, with suitable reverse-voltage margin. VSYS allows 1.8–5.5 V; this build uses verified 5 V before the diode, never the boost's 12 V. Pico W power guidance (https://datasheets.raspberrypi.com/picow/pico-w-datasheet.pdf).

USB data assembly: TP2/TP3 are small solder pads. Keep the data pair short, routed together and away from the boost converter; provide strain relief and verify USB enumeration. For Wi-Fi-only operation, leave D+/D- individually insulated. Alternatively use a proper micro-USB plug breakout for data rather than soldering the pads; do not mix the two data paths.

One USB host at a time. While D+/D- are attached to the DGX through the USB-C board, do not plug a computer into the Pico's micro-USB socket. The socket and test pads share the same USB bus. A VSYS diode protects power sources, not against two USB hosts being connected together. Disconnect the breakout's data connection before using the socket for programming.

### Check the current budget

The standard fan is rated up to 0.13 A at 12 V / 1.56 W. At an assumed 85% converter efficiency, the fan alone draws about 0.37 A at 5 V, plus Pico consumption and startup margin. This is an estimate, not a measured load. Fan ratings (https://www.noctua.at/en/products/nf-a14-pwm/specifications).

Verify the USB source's available current, breakout/cable limits and converter continuous/startup ratings. The JRC-B008's CC termination remains unverified; the connector's 3 A rating does not establish the source's current allowance. Do not use Pico's 3.3 V output to power the motor.

### Keep 12 V off the USB rail

The boost output feeds only the motor branch. A USB-PD trigger requesting more than 5 V is not equivalent to this arrangement. Never feed that voltage into the Pico's USB socket or power pins.

Preserve a proper USB data path to the Pico. Do not splice or parallel USB data lines to create a hub.

Unresolved hardware detail: power sequencing. The fan's PWM input has an internal pull-up. With direct GPIO wiring, do not leave the fan powered while the Pico is unpowered. For bench tests, enable the fan supply only after the Pico is running; disable it before unplugging, resetting or flashing the Pico. One shared USB source alone does not guarantee this sequence. Before unattended use, verify sequencing or design a suitable power-off-tolerant signal interface. The proposed switch above is not assumed to be installed.

Interface basis: Noctua PWM electrical specification (https://cdn.noctua.at/media/Noctua_PWM_specifications_white_paper.pdf). The sequencing precaution is a design constraint for this direct-GPIO circuit, not a claim that the fan has a built-in sequencing feature.

03 / Board orientation

## Find the physical Pico pins

Component side facing you, micro-USB connector at the top. Physical pin numbers are not GPIO numbers: GP15 is physical pin 20, not pin 15.

Figure 3. Physical numbering checked against the official Raspberry Pi Pico W pinout (https://datasheets.raspberrypi.com/picow/PicoW-A4-Pinout.pdf). Power enters VSYS / pin 39 through the added diode. USB test pads are on the underside and are not drawn in this component-side locator.

Earlier wiring correction: tach feedback now uses GP13, not the old GP14 assignment. CircuitPython pulse counting uses a separate PWM slice from GP15; keep GP12/GP13 free of other PWM uses.

04 / RPM measurement circuit

## RPM feedback and PWM are different wires

Figure 4. A strong 3.3 V pull-up and capacitor produce a cleaner tach signal; neither component connects to the blue PWM wire.

### Green: measured rotation

The fan's open-collector tach output gives two pulses per revolution. Pull it up only to the Pico's 3.3 V rail. At 50 pulses/second, measured speed is 1,500 RPM. Noctua currently recommends an external 1 kΩ pull-up and a 1 µF non-polarized capacitor to ground when noise affects RPM readings. Noctua RPM guidance (https://www.noctua.at/en/support/faqs/microcontroller-guide-pwm-setup-and-rpm-monitoring).

The firmware always attempts to count GP13 falling edges. Missing feedback cannot distinguish a stopped fan, missing motor power, an open tach wire, or a bad pull-up/ground connection.

### Blue: requested speed

The current firmware outputs direct 3.3 V, 25 kHz PWM. No external pull-up or inverting transistor is part of this design. Noctua recommends push-pull drive; do not substitute a generic open-collector circuit without reviewing the interface. PWM drive specification (https://cdn.noctua.at/media/Noctua_PWM_specifications_white_paper.pdf).

Control the blue signal, not the yellow motor supply. PWM percentage is not an exact RPM target; the current code does not perform closed-loop RPM regulation.

05 / Commissioning

## First power-up checklist

1. Unplug all power. Confirm the fan label says NF-A14 PWM, 12 V. Check connector numbering, secure terminals and insulate exposed conductors.
2. Verify the power wiring. Confirm USB-C V is 5 V before connecting the Pico. With power off, check diode polarity, ground continuity and no accidental connection from boost OUT+ to a Pico rail. Do not use continuity mode on a powered circuit.
3. Test the converter separately. Keep fan and Pico disconnected. Power the converter and measure a regulated +12 V between OUT+ and OUT-. Check polarity; disconnect power again before assembly.
4. Connect the completed circuit. Start with the fan branch disabled. Power the Pico through VSYS from the verified USB-C 5 V branch and let the application boot, then enable the fan branch. Keep fingers, leads and tools clear.
5. Check under load. Verify 12 V remains stable at the fan and there are no Pico resets, overheated parts or loose connections. If anything is abnormal, remove power.
6. Test speed control. Use the existing dashboard to request full speed, a middle duty and off. Allow for the startup boost. A command timeout can restore full speed; this is not necessarily a wiring fault.
7. Check RPM. Compare the reported RPM at full and middle speed. If it remains zero, verify the shared ground, green wire, 1 kΩ pull-up, and 1 µF filter; do not assume a PWM display proves physical rotation.

What to expect: the standard NF-A14 PWM is specified for 0 RPM at 0% PWM and up to 1,500 RPM at full speed without the Low-Noise Adaptor. Off is a speed command, not electrical isolation: the yellow wire still carries 12 V. Model specifications (https://www.noctua.at/en/products/nf-a14-pwm/specifications).

### Quick diagnosis

Observation | Check first
Always runs at full speed | Blue wire on GP15 / pin 20, shared ground, active command and timeout state. An unconnected PWM input defaults to full speed.
No RPM, but the fan spins | Green on GP13 / pin 17, common ground, 1 kΩ pull-up to 3.3 V, 1 µF capacitor to ground, and connection continuity. RPM wiring does not supply the motor.
Pico resets when fan starts | USB current budget, converter startup draw, cable losses and loose power connections. Do not compensate by feeding 12 V into the Pico.
Fan does not run | Measured 12 V and polarity at the fan, physical obstruction and requested duty. Power down before correcting wiring.

Electrical behaviour reference: Noctua troubleshooting guide (https://www.noctua.at/en/support/faqs/microcontroller-guide-pwm-setup-and-rpm-monitoring).

06 / Hardware vs. software status

## What works now, what comes next

Now: Wi-Fi dashboard, PWM commands and automatic tach counting on GP13. The USB-C V branch supplies Pico power through VSYS. A working USB data connection also provides a filesystem connection and a debug console; V and GND alone do not. The firmware starts at full PWM and normally returns to full PWM after its command timeout.

DGX integration: the included Linux service reads CPU/GPU temperature and renews automatic fan commands over Wi-Fi. A USB cable alone does not provide temperature-based control; there is no USB serial command protocol.

Before unattended use: validate the actual boost/USB hardware, power sequencing and thermal behaviour. The existing software fallback does not guarantee cooling through loss of power, a reset or a frozen processor.

Reference wiring for this experimental repository, not a certified schematic. Diagrams are original illustrations based on linked manufacturer references and current project code. The USB-C breakout is identified as JRC-B008 from prototype source material; its actual CC wiring, the converter model and every physical assembly must be confirmed by the builder.

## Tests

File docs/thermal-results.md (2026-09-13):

# DGX Spark thermal comparison

Test date: **13 September 2026**

The supplied comparison contains separate temperature traces for a baseline run
without the external fan and an updated run with the fan. It reports GPU and CPU
summary statistics and a point-by-point delta chart over roughly 80 minutes.

[Open the original one-page PDF report](results/dgx-fan-temperature-2026-09-13.pdf).

## Published measurements

| Statistic | GPU, no fan | GPU, with fan | With fan minus baseline | CPU, no fan | CPU, with fan | With fan minus baseline |
| --- | ---: | ---: | ---: | ---: | ---: | ---: |
| Median | 63.5 °C | 64.0 °C | +0.5 °C | 73.6 °C | 72.2 °C | -1.4 °C |
| Average | 60.8 °C | 62.1 °C | +1.3 °C | 68.0 °C | 69.8 °C | +1.8 °C |
| Maximum | 78.0 °C | 68.0 °C | **-10.0 °C** | 91.6 °C | 76.7 °C | **-14.9 °C** |
| Minimum | 42.0 °C | 39.0 °C | -3.0 °C | 44.0 °C | 40.7 °C | -3.3 °C |
| Standard deviation | 11.2 °C | 7.3 °C | **-3.9 °C** | 14.8 °C | 9.3 °C | **-5.5 °C** |

Negative deltas are cooler or less variable. Positive deltas are warmer.

## Interpretation

The external fan substantially reduced the highest recorded temperatures:
10.0 °C lower for the GPU and 14.9 °C lower for the CPU. The standard deviations
also fell by 3.9 °C and 5.5 °C, consistent with a more stable temperature trace.

The same data does **not** show a lower average temperature. Average GPU and CPU
temperatures were 1.3 °C and 1.8 °C higher with the fan, and the GPU median was
0.5 °C higher. The strongest supported conclusion from this run is therefore
reduced peaks and variability - not universally lower temperature.

## Limits of the comparison

The report does not record enough experimental detail for a controlled benchmark.
In particular, it does not state:

- the exact workload or whether both runs used an identical timed script;
- ambient temperature and room airflow;
- the fan position, PWM duty, or control curve used during the fan run;
- the DGX Spark software/power mode and internal fan behavior;
- sampling cadence, raw timestamps, or a formal warm-up period; or
- whether the two traces contain perfectly paired samples.

Those omissions can affect averages and point-by-point deltas. Treat this as a
useful build result, not a general performance guarantee.

## Suggested reproduction protocol

1. Record ambient temperature and place the DGX in the same location for both runs.
2. Use a scripted workload with fixed duration, power mode, model/data, and idle
   warm-up/cool-down periods.
3. Log GPU, CPU, fan PWM, tach RPM, power, and timestamps at a fixed cadence.
4. Run baseline and fan conditions in alternating order, with at least three runs
   per condition.
5. Publish raw CSV data and the exact analysis script alongside the summary.
6. Compare peak, median, average, standard deviation, time above thresholds, and
   workload performance so cooling is not confused with a workload difference.

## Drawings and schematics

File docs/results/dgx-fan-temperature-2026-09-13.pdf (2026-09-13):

### DGX External Fan - Temperature Comparison

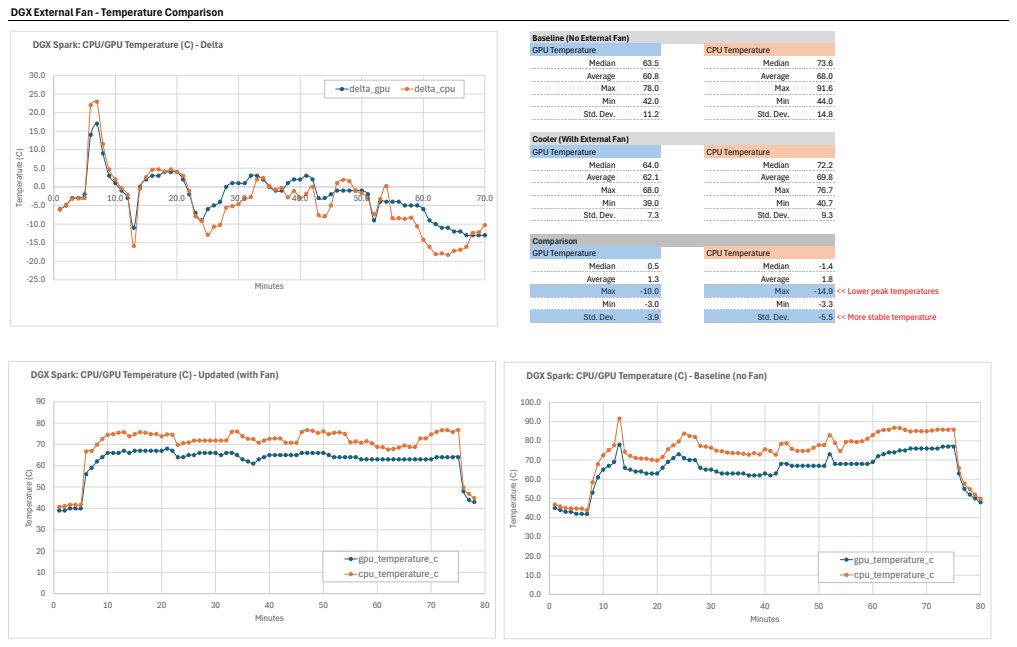
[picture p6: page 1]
GPU Temperature; CPU Temperature; Median; Average; Max; Min; Std. Dev.; Comparison; -14.9 << Lower peak temperatures; -5.5 << More stable temperature; Temperature (C); Minutes; delta_gpu; delta_cpu

Baseline (No External Fan)

DGX Spark: CPU/GPU Temperature (C) - Delta

Cooler (Wilh External Fan)

DGX Spark: CPU/GPU Temperature (C) - Updated (with Fan)

DGX Spark: CPU/GPU Temperature (C) - Baseline (no Fan)

gpu_temperature_c cpu_temperature_c

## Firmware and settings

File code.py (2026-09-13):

"""CircuitPython entry point for the DGX Spark external fan controller."""

import os
import time

import board
import pwmio

from fan_control import FanControl

PWM_PIN = board.GP15  # Physical pin 20 -> fan pin 4 (blue).
TACH_PIN = board.GP13  # Physical pin 17 -> fan pin 3 (green), optional.


class TachDebug:
    """Observe the existing counter without resetting or reclaiming its pin."""

    def __init__(self, tach):
        self.tach = tach
        self.last_time = time.monotonic_ns()
        self.last_count = None
        if tach is not None:
            try:
                self.last_count = tach.count
            except Exception:
                pass

    def report(self, pwm):
        now = time.monotonic_ns()
        elapsed = now - self.last_time
        if elapsed < 5_000_000_000:
            return
        self.last_time = now
        if self.tach is None:
            print("TACH GP13 (pin 17): unavailable; check boot warnings")
            return
        try:
            count = self.tach.count
        except Exception as error:
            self.last_count = None
            print("TACH GP13 (pin 17): counter read failed ({})".format(type(error).__name__))
            return
        pulses = None if self.last_count is None else (count - self.last_count) & 0xFFFFFFFF
        rpm = None if pulses is None else round(pulses * 60_000_000_000 / (2 * elapsed))
        self.last_count = count
        print("TACH GP13 (pin 17): total={} | pulses={} / {:.2f}s | window_RPM={} | PWM={}%".format(
            count, pulses, elapsed / 1_000_000_000, rpm, pwm,
        ))


class ConfigurationError(ValueError):
    """A settings error that is safe to print without exposing its value."""


def setting(name, default=None):
    try:
        return os.getenv(name, default)
    except (ValueError, TypeError, OSError):
        raise ConfigurationError("Cannot read " + name + "; check settings.toml syntax")


def flag(name, default="0"):
    value = setting(name, default)
    if str(value) not in ("0", "1"):
        raise ConfigurationError(name + " must be 0 or 1")
    return str(value) == "1"


def integer(name, default, minimum, maximum, allow_zero=False):
    value = setting(name, default)
    try:
        if type(value) not in (str, int):
            raise ValueError()
        value = int(value)
        if not minimum <= value <= maximum and not (allow_zero and value == 0):
            raise ValueError()
    except (ValueError, TypeError):
        message = name + " must be an integer from {} to {}".format(minimum, maximum)
        raise ConfigurationError(message + (", or 0" if allow_zero else ""))
    return value


def run():
    pwm = pwmio.PWMOut(PWM_PIN, frequency=25_000, duty_cycle=65535)
    tach = None
    network = None
    try:
        try:
            import countio
            import digitalio
            tach = countio.Counter(
                TACH_PIN, edge=countio.Edge.FALL, pull=digitalio.Pull.UP
            )
        except Exception as error:
            print("RPM unavailable: GP13 counter initialization failed ({})".format(
                type(error).__name__
            ))

        configuration_ok = False
        try:
            remote = flag("WIFI_ENABLED")
            default_duty = 100 if remote else integer("FAN_DUTY_PERCENT", 60, 20, 100, True)
            timeout = integer("FAN_COMMAND_TIMEOUT", 30, 5, 300) if remote else 30
            controller = FanControl(
                pwm, tach, remote=remote, default_duty=default_duty, timeout=timeout,
            )
            configuration_ok = True
        except ConfigurationError as error:
            print("Configuration warning:", str(error))
            controller = FanControl(pwm, tach, remote=True)
            controller.failsafe("configuration_error")

        try:
            controller.curve.load()
        except (OSError, ValueError, TypeError):
            print("Curve settings unavailable/invalid; using draft defaults with automatic control enabled.")

        if configuration_ok and remote:
            try:
                from wifi_control import WiFiControl, WiFiConfigurationError
            except ImportError:
                controller.failsafe("wifi_unavailable")
                print("Wi-Fi disabled: check wifi_control.py and lib/adafruit_httpserver")
            else:
                try:
                    network = WiFiControl(
                        controller,
                        ssid=setting("WIFI_SSID"),
                        password=setting("WIFI_PASSWORD"),
                        web_username=setting("FAN_WEB_USERNAME"),
                        web_password=setting("FAN_WEB_PASSWORD"),
                        hostname=setting("DEVICE_NAME", "dgx-fan"),
                        port=integer("FAN_HTTP_PORT", 80, 1, 65535),
                        ipv4_address=setting("WIFI_IPV4_ADDRESS"),
                        ipv4_netmask=setting("WIFI_IPV4_NETMASK"),
                        ipv4_gateway=setting("WIFI_IPV4_GATEWAY"),
                        ipv4_dns=setting("WIFI_IPV4_DNS"),
                    )
                    print("Wi-Fi control enabled; full speed until a valid command arrives")
                except (ConfigurationError, WiFiConfigurationError) as error:
                    controller.failsafe("configuration_error")
                    print("Wi-Fi disabled:", str(error))
                except Exception as error:
                    controller.failsafe("wifi_unavailable")
                    print("Wi-Fi initialization failed ({}); check Wi-Fi and lib/adafruit_httpserver".format(
                        type(error).__name__
                    ))
        elif configuration_ok:
            print("Standalone mode: startup boost, then configured duty")
        if controller.state in ("configuration_error", "wifi_unavailable"):
            print("Holding 100% PWM; correct settings/libraries and reload code.py")
        print("Boot complete; fan wiring is not required. PWM output does not confirm fan rotation.")
        print("Tach sensing is automatic; diagnostics every 5 seconds show falling-edge counts")
        tach_debug = TachDebug(tach)
        last_report = None
        while True:
            controller.tick()
            if network is not None:
                network.poll()
            status = controller.status()
            # Compare displayed values only; command age changes even when idle.
            report = (status["applied_duty"], status["rpm"], status["state"])
            if report != last_report:
                print("PWM: {}% | RPM: {} | {}".format(*report))
                last_report = report
            tach_debug.report(status["applied_duty"])
            time.sleep(0.05)
    except Exception as error:
        pwm.duty_cycle = 65535
        # Do not print exception messages that could include network credentials.
        print("Controller error:", type(error).__name__)
        print("Holding 100% PWM; check settings/libraries and reload code.py")
        while True:
            time.sleep(1)
    finally:
        try:
            if network is not None:
                network.close()
        finally:
            if tach is not None:
                tach.deinit()
            pwm.deinit()


if __name__ == "__main__":
    try:
        run()
    except KeyboardInterrupt:
        print("Controller stopped; PWM released. Reload code.py to restart.")

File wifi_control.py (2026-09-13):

"""Local Wi-Fi API with settings-backed login and browser sessions."""

import binascii
from errno import EAGAIN, ECONNRESET, ETIMEDOUT
import os
import time

class WiFiConfigurationError(ValueError):
    """A configuration error whose message contains no credential values."""


def validate_login(web_username, web_password):
    if (not isinstance(web_username, str) or not web_username
            or not isinstance(web_password, str) or not web_password):
        raise WiFiConfigurationError(
            "FAN_WEB_USERNAME and FAN_WEB_PASSWORD are required in settings.toml"
        )


def send_bytes_bounded(connection, buffer, clock=time.monotonic_ns,
                       stall_ns=3_000_000_000):
    """Send a buffer without allowing an abandoned client to freeze the server."""
    sent = 0
    stalled_at = clock()
    view = memoryview(buffer)
    while sent < len(buffer):
        try:
            count = connection.send(view[sent:])
        except OSError as error:
            if error.errno == ECONNRESET:
                raise
            if error.errno != EAGAIN:
                raise
            count = 0
        now = clock()
        if count:
            sent += count
            stalled_at = now
        elif now - stalled_at >= stall_ns:
            raise OSError(ETIMEDOUT, "client send stalled")
    return sent


def make_server(pool, controller, web_username, web_password, *, web_root="www"):
    validate_login(web_username, web_password)
    from adafruit_httpserver import GET, POST, FileResponse, JSONResponse, Redirect, Server

    class BoundedFileResponse(FileResponse):
        def _send_bytes(self, connection, buffer):
            self._size += send_bytes_bounded(connection, buffer)

    def asset(request, filename):
        return BoundedFileResponse(
            request, filename, root_path=web_root,
            headers={"Cache-Control": "public, max-age=3600"},
        )

    # Explicit asset routes only: settings and firmware are never served.
    server = Server(pool, debug=False)
    server.socket_timeout = 0.5
    server.headers = {"Connection": "close", "Cache-Control": "no-store",
                      "X-Content-Type-Options": "nosniff", "X-Frame-Options": "DENY",
                      "Referrer-Policy": "no-referrer",
                      "Content-Security-Policy": "default-src 'self'; script-src 'self'; style-src 'self'; connect-src 'self'; img-src 'self'; frame-ancestors 'none'; base-uri 'none'; form-action 'none'"}
    sessions = []
    cookie_name = "fan_session"

    def require_json(request):
        content_type = request.headers.get("Content-Type", "")
        if content_type.split(";", 1)[0].strip().lower() != "application/json":
            return JSONResponse(request, {"error": "Content-Type must be application/json"},
                                status=(415, "Unsupported Media Type"))
        return None

    def new_session():
        token = binascii.hexlify(os.urandom(24)).decode("ascii")
        sessions.append(token)
        if len(sessions) > 4:
            sessions.pop(0)
        return token

    def authorized(request):
        return request.cookies.get(cookie_name) in sessions

    def deny(request):
        return JSONResponse(request, {"error": "login required"},
                            status=(401, "Unauthorized"))

    @server.route("/", GET)
    def dashboard(request):
        if not authorized(request):
            return Redirect(request, "/login")
        return BoundedFileResponse(request, "index.html", root_path=web_root)

    @server.route("/login", GET)
    def login_page(request):
        if authorized(request):
            return Redirect(request, "/")
        return BoundedFileResponse(request, "login.html", root_path=web_root)

    @server.route("/dashboard.css", GET)
    def stylesheet(request):
        return asset(request, "dashboard.css")

    @server.route("/dashboard.js", GET)
    def javascript(request):
        return asset(request, "dashboard.js")

    @server.route("/dashboard-loader.js", GET)
    def dashboard_loader(request):
        return asset(request, "dashboard-loader.js")

    @server.route("/login.js", GET)
    def login_javascript(request):
        return asset(request, "login.js")

    @server.route("/maximize-2.svg", GET)
    def expand_icon(request):
        return asset(request, "maximize-2.svg")

    @server.route("/x.svg", GET)
    def close_icon(request):
        return asset(request, "x.svg")

    @server.route("/api/session", GET)
    def session_status(request):
        return JSONResponse(request, {"authenticated": authorized(request)})

    @server.route("/api/login", POST)
    def login(request):
        error = require_json(request)
        if error is not None:
            return error
        try:
            data = request.json()
            valid = (isinstance(data, dict) and len(data) == 2
                     and data.get("username") == web_username
                     and data.get("password") == web_password)
        except (ValueError, TypeError):
            valid = False
        if not valid:
            return JSONResponse(request, {"error": "invalid username or password"},
                                status=(401, "Unauthorized"))
        token = new_session()
        return JSONResponse(
            request, {"authenticated": True},
            cookies={cookie_name: token + "; Path=/; HttpOnly; SameSite=Strict"},
        )

    @server.route("/api/logout", POST)
    def logout(request):
        error = require_json(request)
        if error is not None:
            return error
        token = request.cookies.get(cookie_name)
        if token in sessions:
            sessions.remove(token)
        return JSONResponse(
            request, {"authenticated": False},
            cookies={cookie_name: "; Path=/; HttpOnly; SameSite=Strict; Max-Age=0"},
        )

    @server.route("/api/dashboard", GET)
    def dashboard_status(request):
        if not authorized(request):
            return deny(request)
        controller.tick()
        return JSONResponse(request, controller.status())

    @server.route("/api/history", GET)
    def history(request):
        if not authorized(request):
            return deny(request)
        controller.tick()
        try:
            before = request.query_params.get("before")
            before = None if before is None else int(before)
            limit = int(request.query_params.get("limit", "120"))
            data = controller.history.page(before, limit)
        except (ValueError, TypeError):
            return JSONResponse(request, {"error": "invalid history page; limit 1-120, before >= 0"},
                                status=(400, "Bad Request"))
        return JSONResponse(request, data)

    @server.route("/api/curve", GET)
    def get_curve(request):
        if not authorized(request):
            return deny(request)
        return JSONResponse(request, controller.curve.status())
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

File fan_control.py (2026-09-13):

"""Fan state, startup boost, RPM sampling and remote-command timeout."""

import time

from fan_history import FanHistory
from fan_curve import FanCurve


def duty_value(percent):
    if type(percent) not in (int, float) or (percent != 0 and not 20 <= percent <= 100):
        raise ValueError("duty must be 0 (off), or a number from 20 to 100")
    return round(percent * 65535 / 100)


class FanControl:
    def __init__(self, pwm, tach=None, *, remote=False, default_duty=60,
                 timeout=30, clock=time.monotonic_ns):
        duty_value(default_duty)
        if not 5 <= timeout <= 300:
            raise ValueError("command timeout must be between 5 and 300 seconds")
        self.pwm = pwm
        self.tach = tach
        self.remote = remote
        self.clock = clock
        self.history = FanHistory(clock)
        self.curve = FanCurve()
        self.timeout_ns = timeout * 1_000_000_000
        self.last_command = None
        self.target = 100 if remote else default_duty
        self.applied = 100
        self.state = "awaiting_command" if remote else "startup"
        now = clock()
        self.boost_until = now + 2_000_000_000
        self.sample_time = now
        self.sample_count = tach.count if tach is not None else 0
        self.rpm = None
        self.pwm.duty_cycle = 65535

    def _apply(self, duty):
        if duty != self.applied:
            self.pwm.duty_cycle = duty_value(duty)
            self.applied = duty

    def command(self, duty):
        duty_value(duty)
        now = self.clock()
        if duty == 0:
            self.boost_until = None
        elif self.applied == 0:
            self.boost_until = now + 2_000_000_000
        self.target = duty
        self.last_command = now
        self.state = "controlled"
        self.tick()

    def failsafe(self, reason):
        self.last_command = None
        self.boost_until = None
        self.target = 100
        self.state = reason
        self._apply(100)

    def tick(self):
        now = self.clock()
        if (self.remote and self.last_command is not None
                and now - self.last_command >= self.timeout_ns):
            self.failsafe("command_timeout")
        if self.boost_until is not None and now >= self.boost_until:
            self.boost_until = None
            if self.state == "startup":
                self.state = "standalone"
        self._apply(100 if self.boost_until is not None else self.target)

        elapsed = now - self.sample_time
        if self.tach is not None and elapsed >= 2_000_000_000:
            count = self.tach.count
            pulses = (count - self.sample_count) & 0xFFFFFFFF
            self.rpm = round(pulses * 60_000_000_000 / (2 * elapsed))
            self.sample_count, self.sample_time = count, now
        self.history.record(self.rpm, self.applied)

    def status(self):
        age = None if self.last_command is None else (
            self.clock() - self.last_command
        ) // 1_000_000_000
        result = {
            "mode": "wifi" if self.remote else "standalone",
            "state": self.state,
            "requested_duty": self.target,
            "applied_duty": self.applied,
            "startup_boost": self.boost_until is not None,
            "rpm": self.rpm,
            "command_age_seconds": age,
            "command_timeout_seconds": self.timeout_ns // 1_000_000_000,
            "automatic_control_active": self.curve.automatic_control_active,
        }
        result.update(self.history.status())
        return result

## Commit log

2026-09-13 Add project visuals and printable models
    [face-hugger-fan-dgx-spark-arms.stl, face-hugger-fan-dgx-spark-body.stl]
2026-09-13 Show real build and link printable parts
2026-09-13 Enhance README with additional project details
    Updated project description to include temperature tracking and automatic fan control features.
2026-09-13 Revise README for clarity and safety information
    Clarified functionality of the RPi Pico W and updated safety caution.
